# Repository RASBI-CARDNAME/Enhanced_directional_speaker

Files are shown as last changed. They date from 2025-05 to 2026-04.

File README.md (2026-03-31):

# 🔊 STM32 기반 초지향성 스피커 (Ultrasonic Directional Speaker)

## 1. 프로젝트 개요 (Overview)
초음파의 직진성과 공기의 비선형성(Non-linearity)을 이용하여 특정 영역에만 소리를 전달하는 **초지향성 스피커(Parametric Speaker)** 프로젝트입니다.
오픈소스 프로젝트(Arduino 기반)를 분석하여 **STM32 HAL 라이브러리로 직접 포팅**하였으며, **하드웨어 회로 개선(LC 공진 및 노이즈 필터링)을 통해 음질과 출력을 대폭 향상**시켰습니다.

*   **원본 레포지토리:** [gururise/directional_speaker](https://github.com/gururise/directional_speaker)
*   **원본 레포 작동 영상:** [YouTube](https://www.youtube.com/watch?v=9hD5FPVSsV0)
*   **이 레포 작동 영상 및 측정치:** [Naver Blog](https://blog.naver.com/hiho0718/224090581630)
  
*   **개선 사항:**
    1.  **SW:** Arduino 코드를 STM32CubeIDE(HAL) 환경으로 포팅 및 PWM 로직 최적화
    2.  **HW:** TC4427 드라이버 안정화 및 LC 공진 회로 추가를 통한 출력 효율 증대

---

## 2. 기술 스택 (Tech Stack)
*   **MCU:** STM32F103C8T6 (WeAct BluePill Plus)
*   **IDE/Language:** STM32CubeIDE, C (HAL Library)
*   **Hardware:** KiCad (Schematic), TC4427 (MOSFET Driver), Ultrasonic Transducers (40kHz)
*   **Theory:** Amplitude Modulation (AM), PWM Carrier Generation

---

## 3. 핵심 개선 사항 (Key Improvements)

### 🛠️ 하드웨어 (Hardware)
단순한 드라이버 구동을 넘어, 물리적 특성을 고려한 회로 튜닝을 진행했습니다.
*   **LC 공진 회로(Resonant Circuit) 구성:**
    *   초음파 트랜스듀서(Transducer)가 가진 고유 커패시턴스 성분을 고려하여, 인덕터(Inductor)를 추가해 LC 공진을 유도했습니다.
    *   이를 통해 전력 효율을 높이고 스피커 출력을 극대화했습니다. (트랜스듀서 개수에 맞춰 인덕턴스 값 튜닝)
*   **전원 안정화:**
    *   TC4427 MOSFET 드라이버에 **Decoupling Capacitor**를 추가하여 고속 스위칭 시 발생하는 전압 강하와 노이즈를 억제, 음질을 개선했습니다.

### 💻 소프트웨어 (Firmware)
*   **HAL 라이브러리 포팅:**
    *   기존 Arduino의 레지스터 직접 제어 방식을 분석하여, STM32 HAL 및 LL 드라이버 구조에 맞게 재설계했습니다.
*   **PWM 신호 무결성 확보:**
    *   40kHz Carrier 주파수를 생성하고, ADC로 입력받은 오디오 신호에 따라 Duty Cycle을 실시간으로 변조합니다.

---

## 4. 트러블 슈팅 (Troubleshooting) 🚀핵심

### Q1. 볼륨 증가 시 음질 저하 및 클리핑 현상
*   **원인:** PWM 듀티 사이클이 0%나 100%에 근접할 경우, 파형이 DC(직류)에 가까워지며 트랜스듀서의 응답성이 떨어지고 신호가 찌그러짐.
*   **해결:** **Software Limiter 구현.**
    *   PWM Duty Cycle의 범위를 **33% ~ 88% (또는 유효 구간)** 내로 제한하는 로직을 추가하여, 변조 한계를 방지하고 음량 헤드룸(Headroom)을 확보함. 임의로 듀티 사이클 범위를 변경시 음질 저하가 발생 할 수 있으니 주의.

### Q2. 40kHz 트랜스듀서 구동 효율 문제
*   **원인:** 트랜스듀서는 용량성(Capacitive) 부하이기 때문에 단순 구동 시 증폭 단 전류 소모가 크고 심한 열이 발생.
*   **해결:** 직렬 인덕터를 추가하여 회로가 **특정 주파수(40kHz)에서 공진**하도록 설계, 임피던스 매칭을 통해 구동 효율 개선.

---

## 5. 하드웨어 구성 (Components)
*   **MCU Board:** WeAct BluePill Plus (STM32F103C8T6)
*   **Driver IC:** TC4427 (High-Speed MOSFET Driver)
*   **Transducer:** V40AN16T (40kHz) x 42 units array
*   **Pre-Amp:** LM358 (Audio Input Bias & Amplification)

## 트랜스듀서
40kHz에서 작동하는 V40AN16T 트랜스듀서를 42개 사용했습니다.
이 주파수와 일치하는 트랜스듀서를 사용해야 합니다.

## 다른 연산 증폭기나 MOSFET 드라이버를 사용할 수 있나요?
상관 없습니다. 부품을 자유롭게 업그레이드할 수 있습니다.

예를 들어, 더 나은 성능을 위해 MOSFET 드라이버 + 개별 MOSFET 구성을 사용할 수 있습니다.
아시다시피, PWM 신호를 증폭하기 위해 MOSFET 드라이버만 사용하는 것은 이상적이지 않지만, 이 작품에서는 잘 작동합니다.

## 데드타임 설정이 되어있나요?
회로도를 따라 구현한다면 데드타임이 필요하지 않지만, 다른 증폭 방식을 사용할때는 데드타임을 설정해주어야 합니다.

---

## 📜 License
*   Original Code: GPL 2.0 License (by gururise)
*   Modified Code: GPL 2.0 License

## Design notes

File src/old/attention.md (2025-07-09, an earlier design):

## These codes are for the Arduino IDE using the STM32 library.

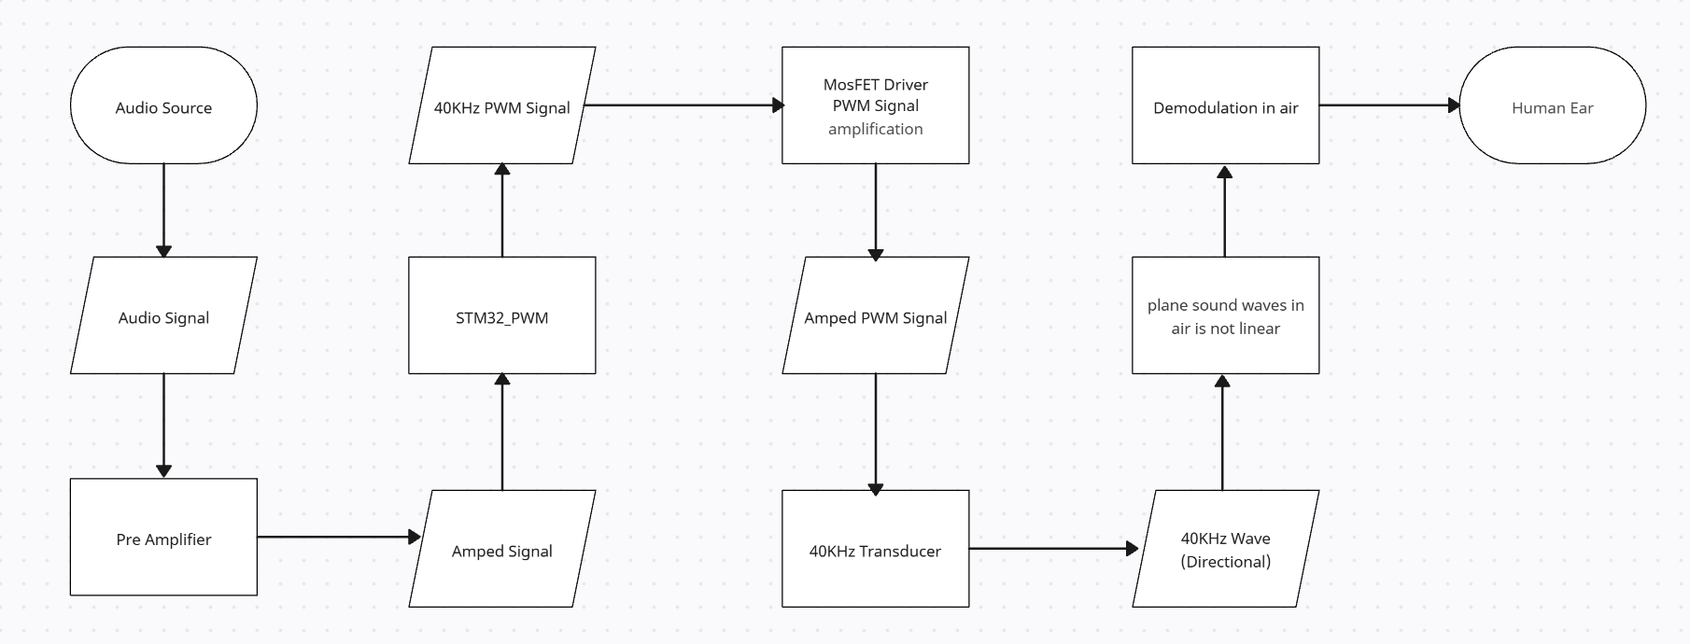
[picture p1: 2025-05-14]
Images/block_diagram.png

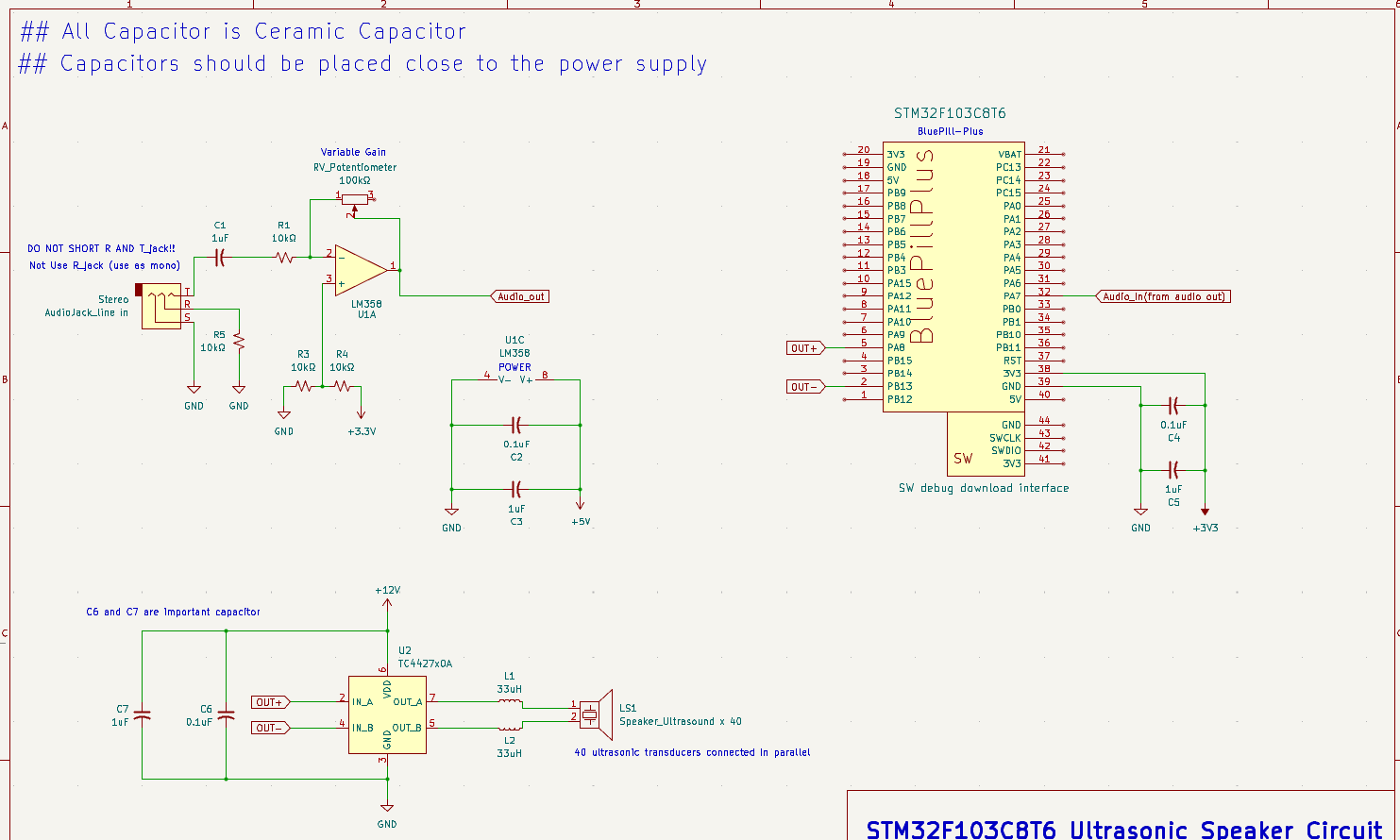
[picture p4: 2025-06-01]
circuit_diagram/circuit_4.0.png

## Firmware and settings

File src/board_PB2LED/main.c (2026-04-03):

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
/* Includes ------------------------------------------------------------------*/
#include "main.h"

/* USER CODE BEGIN PTD */
/* ADC State define */
typedef enum {
	ADC_STATE_NONE,
	ADC_STATE_HALF,
	ADC_STATE_FULL
}ADC_DMA_state_t;

/* USER CODE END PTD */

/* USER CODE BEGIN PD */
#define PWM_OVERFLOW 1500 //(PWM_HALF+600)
#define PWM_HALF 900 // (PWM_ARR / 2), this is mid value of PWM duty cycle
#define PWM_UNDERFLOW 300 // (PWM_HALF-600)
#define ADC_MID_VALUE 2048 //ADC input range / 2 = 2048

#define BUFFER_SIZE 100
#define BUFFER_SIZE_HALF 50

/* USER CODE END PD */

ADC_HandleTypeDef hadc1;
DMA_HandleTypeDef hdma_adc1;

TIM_HandleTypeDef htim1;
TIM_HandleTypeDef htim3;

/* USER CODE BEGIN PV */
volatile uint16_t audio_buffer[BUFFER_SIZE]; //audio signal buffer
volatile ADC_DMA_state_t adc_conv_flag = ADC_STATE_NONE;
/* USER CODE END PV */

void SystemClock_Config(void);
static void MX_GPIO_Init(void);
static void MX_DMA_Init(void);
static void MX_ADC1_Init(void);
static void MX_TIM1_Init(void);
static void MX_TIM3_Init(void);
/* USER CODE BEGIN PFP */

/*Check MCU Status*/
static inline void Heartbeat();

/* caculate PWM duty cycle */
static inline void audio_dsp(volatile uint16_t *buf, uint16_t start_index, uint16_t last_index, size_t cal_size);

/* USER CODE END PFP */

/* USER CODE BEGIN 0 */

/*Check MCU Status*/
static inline void Heartbeat() {
	static uint32_t prev_tick_val = 0;

	if (HAL_GetTick() - prev_tick_val > 500) {
		prev_tick_val = HAL_GetTick();
		HAL_GPIO_TogglePin(GPIOB, GPIO_PIN_2);
	}
}

static inline void audio_dsp(volatile uint16_t *buf, uint16_t start_index, uint16_t last_index, size_t cal_size) {

	/* array for save calculation result */
	static int32_t deviation;

	/* caculate PWM deviation */
	for (int i = start_index; i<last_index+1; i++) {
		deviation = ((((int32_t)buf[i]-(int32_t)ADC_MID_VALUE)*600)>>11)+PWM_HALF;

		/* check value */
		if (deviation > PWM_OVERFLOW) {
			deviation = PWM_OVERFLOW;
		} else if (deviation < PWM_UNDERFLOW) {
			deviation = PWM_UNDERFLOW;
		}

		/* final pwm_out */
		__HAL_TIM_SET_COMPARE(&htim1, TIM_CHANNEL_1,(uint16_t)deviation);
		__HAL_TIM_SET_COMPARE(&htim1, TIM_CHANNEL_2,(uint16_t)deviation);
	}
}

/* USER CODE END 0 */

/**
  * @brief  The application entry point.
  * @retval int
  */
int main(void)
{

  /* MCU Configuration--------------------------------------------------------*/

  /* Reset of all peripherals, Initializes the Flash interface and the Systick. */
  HAL_Init();

  /* Configure the system clock */
  SystemClock_Config();

  /* Initialize all configured peripherals */
  MX_GPIO_Init();
  MX_DMA_Init();
  MX_ADC1_Init();
  MX_TIM1_Init();
  MX_TIM3_Init();
  /* USER CODE BEGIN 2 */
  /* Start PWM Output */
  HAL_TIM_PWM_Start(&htim1, TIM_CHANNEL_1);
  HAL_TIMEx_PWMN_Start(&htim1, TIM_CHANNEL_1);

  HAL_TIM_PWM_Start(&htim1, TIM_CHANNEL_2);
  HAL_TIMEx_PWMN_Start(&htim1, TIM_CHANNEL_2);

  /* Start TIM_3 */
  HAL_TIM_Base_Start(&htim3);

  /* Start ADC with DMA */
  HAL_ADC_Start_DMA(&hadc1, audio_buffer, BUFFER_SIZE);

  /* USER CODE END 2 */

  /* Infinite loop */
  /* USER CODE BEGIN WHILE */
  while (1)
  {
    /* USER CODE END WHILE */

    /* USER CODE BEGIN 3 */
	  Heartbeat();

	  /* PWM duty cycle Calculation */
	  if (adc_conv_flag != ADC_STATE_NONE) {
		  ADC_DMA_state_t current_flag = adc_conv_flag;
		  adc_conv_flag = ADC_STATE_NONE;
		  switch(current_flag) {
		  case ADC_STATE_HALF:
			  //audio_buffer[0]-[49]
			  audio_dsp(audio_buffer,0,BUFFER_SIZE_HALF, BUFFER_SIZE_HALF);
			  break;
		  case ADC_STATE_FULL:
			  //audio_buffer[50]-[99]
			  audio_dsp(audio_buffer,BUFFER_SIZE_HALF,BUFFER_SIZE, BUFFER_SIZE_HALF);
			  break;
		  default:
			  break;
		  }
	  }

  }
  /* USER CODE END 3 */
}

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
/* USER CODE BEGIN 4 */
void HAL_ADC_ConvHalfCpltCallback(ADC_HandleTypeDef* hadc){
	adc_conv_flag = ADC_STATE_HALF;
}

void HAL_ADC_ConvCpltCallback(ADC_HandleTypeDef* hadc) {
	adc_conv_flag = ADC_STATE_FULL;
}

/* USER CODE END 4 */
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


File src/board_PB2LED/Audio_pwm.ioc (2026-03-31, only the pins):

Mcu.UserName=STM32F103C8Tx
PA13.Signal=SYS_JTMS-SWDIO
PA14.Signal=SYS_JTCK-SWCLK
PA7.Signal=ADCx_IN7
PA8.Signal=S_TIM1_CH1
PA9.Signal=S_TIM1_CH2
PB13.Signal=TIM1_CH1N
PB14.Signal=TIM1_CH2N
PB2.GPIO_Label=built_in_LED
PB2.Signal=GPIO_Output
PD0-OSC_IN.Signal=RCC_OSC_IN
PD1-OSC_OUT.Signal=RCC_OSC_OUT

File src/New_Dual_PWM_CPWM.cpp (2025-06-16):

/*
=========================================================================
  Ultrasonic Parametric Speaker Source Code for STM32
  Copyright (C) 2019,2020 Gene Ruebsamen

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
==========================================================================
  Modified by: RASBI
  Date: 2025-06-16
  Description: NEED TEST!!!!!
  
  Final version with dual driver support and improved DSB-SC modulation.
==========================================================================
*/

#include <Arduino.h>
#include <STM32ADC.h>

// --- Configuration ---
#define PWM_OVERFLOW 1800        // 72MHz / 1800 = 40kHz PWM carrier frequency

// Driver 1 Output Pins (TIM1 Channel 1)
#define PWM_OUT_1 PA8
#define PWM_OUT_COMP_1 PB13

// Driver 2 Output Pins (TIM1 Channel 2)
#define PWM_OUT_2 PA9
#define PWM_OUT_COMP_2 PB14

#define ANALOG_PIN PA7           // ADC input pin
#define LED_PIN PB2              // Status/Crash indicator LED
#define maxSamples 1             // DMA buffer size for ADC

// --- Global Objects and Variables ---
HardwareTimer hTimer1 = HardwareTimer(1);
STM32ADC myADC(ADC1);

uint16_t buffer[maxSamples];     // DMA buffer for ADC results
uint8 pins = 7;                  // ADC pin index for PA7
const uint16_t adcMid = 2048;    // Midpoint for 12-bit ADC (assuming 0-3.3V audio input centered at 1.65V)

void isr(void);                  // Timer interrupt service routine declaration

void setup() {
  // --- Pin Initialization ---
  pinMode(ANALOG_PIN, INPUT_ANALOG);
  pinMode(LED_PIN, OUTPUT);

  // Initialize all PWM pins for both drivers
  pinMode(PWM_OUT_1, PWM);
  pinMode(PWM_OUT_COMP_1, PWM);
  pinMode(PWM_OUT_2, PWM);
  pinMode(PWM_OUT_COMP_2, PWM);

  // --- Timer 1 Setup for 40kHz Complementary PWM ---
  hTimer1.pause();
  hTimer1.setPrescaleFactor(1);
  hTimer1.setOverflow(PWM_OVERFLOW);
  
  // Set up a dummy channel to attach the ISR. 
  // The actual PWM modes for CH1 and CH2 will be set via registers.
  hTimer1.setMode(4, TIMER_OUTPUT_COMPARE);
  hTimer1.setCompare(4, PWM_OVERFLOW);
  hTimer1.attachInterrupt(4, isr);

  // --- Direct Register Access for Advanced Timer Features ---
  timer_dev *t = TIMER1;
  timer_reg_map r = t->regs;

  // Enable complementary outputs for both channels in TIM1_CCER register
  bitSet(r.adv->CCER, 0); // CC1E: Enable CH1 output (PA8)
  bitSet(r.adv->CCER, 2); // CC1NE: Enable CH1N complementary output (PB13)
  bitSet(r.adv->CCER, 4); // CC2E: Enable CH2 output (PA9)
  bitSet(r.adv->CCER, 6); // CC2NE: Enable CH2N complementary output (PB14)

  // Start the timer
  hTimer1.refresh();
  hTimer1.resume();

  // Set initial duty cycle to 50% for both channels
  pwmWrite(PWM_OUT_1, PWM_OVERFLOW / 2);
  pwmWrite(PWM_OUT_2, PWM_OVERFLOW / 2);

  // --- ADC and DMA Setup ---
  // Use Timer 3 to trigger ADC conversions at 100kHz
  Timer3.setPeriod(10); // 10 microseconds -> 100kHz sampling rate
  Timer3.setMasterModeTrGo(TIMER_CR2_MMS_UPDATE); // Trigger on update event

  myADC.calibrate();
  myADC.setSampleRate(ADC_SMPR_1_5);
  myADC.setPins(&pins, 1);
  
  // Configure DMA to continuously transfer ADC results to the 'buffer'
  myADC.setDMA(buffer, maxSamples,
               (DMA_MINC_MODE | DMA_CIRC_MODE | DMA_HALF_TRNS | DMA_TRNS_CMPLT), NULL);
               
  myADC.setTrigger(ADC_EXT_EV_TIM3_TRGO); // Set ADC to trigger from Timer 3
  myADC.startConversion();
}

void loop() {
  // Main loop can be used for other tasks.
  // Blinking LED provides a simple visual check that the MCU is not frozen.
  digitalWrite(LED_PIN, HIGH);
  delay(1000);
  digitalWrite(LED_PIN, LOW);
  delay(1000);
}

/**
 * @brief Interrupt Service Routine (ISR) called by Timer 1 at 40kHz.
 * This function performs the Double-Sideband Suppressed-Carrier (DSB-SC)
 * modulation by adjusting the PWM duty cycle based on the audio input.
 */
void isr(void) {
  // 1. Get the latest ADC sample from the DMA buffer and calculate its signed deviation from the center point.
  int16_t deviation = (int16_t)buffer[0] - adcMid;

  // 2. Map the audio deviation to a PWM duty cycle shift.
  // The full audio range (-2048 to +2047) is mapped to the full duty cycle range (0% to 100%).
  int16_t dutyShift = map(deviation, -adcMid, adcMid, -PWM_OVERFLOW / 2 + 1, PWM_OVERFLOW / 2 - 1);

  // 3. Calculate the final duty cycle by adding the shift to the 50% center point.
  // 'constrain' ensures the value stays within the valid range [0, PWM_OVERFLOW-1].
  uint16_t pwmDuty = constrain(PWM_OVERFLOW / 2 + dutyShift, 0, PWM_OVERFLOW - 1);

  // 4. Apply the same duty cycle to both PWM channels.
  // The hardware will automatically generate the complementary signals.
  pwmWrite(PWM_OUT_1, pwmDuty); // Controls Driver 1
  pwmWrite(PWM_OUT_2, pwmDuty); // Controls Driver 2
}

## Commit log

2025-05-06 Update main.cpp
    최적화, 샘플주기 200KHz -> 100KHz
2025-05-06 Delete diagrams/Schematic.png
    old
2025-05-06 circuit diagram
    circuit diagram
    [STM32F103C8T6 Ultrasonic Speaker Circuit.kicad_sch]
2025-05-14 Rename src/main.cpp to Original_small improve.cpp
    Use 100KHz Sampling Rate.
    Use PB2 as LED indicator (built in LED)
2025-06-01 Circuit_4.0
    add decoupling capacitor
    [STM32F103C8T6 Ultrasonic Speaker Circuit.kicad_sch]
2025-06-01 circuit picture
    circuit picture
2025-06-16 Rename circuit_4.0.png to circuit_old.png
    single 4427 with 40 transducer is so hard. 4427`s temp is so high. Be careful.
2025-06-16 Update and rename STM32F103C8T6 Ultrasonic Speaker Circuit.kicad_sch to (OLD)STM32F103C8T6 Ultrasonic Speaker Circuit.kicad_sch
    4.0, outdated
    [(OLD)STM32F103C8T6 Ultrasonic Speaker Circuit.kicad_sch]
2025-06-16 5.0, use this circuit
2025-07-03 Update and rename src/Dual_PWM_Final.ioc to src/board_PB2LED/Dual_PWM_Final.ioc
2025-07-03 Update and rename src/main.c to src/board_PB2LEd/main.c
2025-07-09 Kicad circuit
    [(DUAL)STM32F103C8T6 Ultrasonic Speaker Circuit.kicad_sch]
2025-07-09 Rename (DUAL)STM32F103C8T6 Ultrasonic Speaker Circuit.kicad_sch to Circuit Diagram/(DUAL)STM32F103C8T6 Ultrasonic Speaker Circuit.kicad_sch
    [(DUAL)STM32F103C8T6 Ultrasonic Speaker Circuit.kicad_sch]
2026-03-31 Code Bug Fixes and Improvements
    Code Bug Fixes and Improvements
    [Audio_pwm.ioc, main.c]
2026-03-31 Refactor main.c for dual driver support and modulation
    Updated header comments, modified PWM settings, and improved ADC handling.

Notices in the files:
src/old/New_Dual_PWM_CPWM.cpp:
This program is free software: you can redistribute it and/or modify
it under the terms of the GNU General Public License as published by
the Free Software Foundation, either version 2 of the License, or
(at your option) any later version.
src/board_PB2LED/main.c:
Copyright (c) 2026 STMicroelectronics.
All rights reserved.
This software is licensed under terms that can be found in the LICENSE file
